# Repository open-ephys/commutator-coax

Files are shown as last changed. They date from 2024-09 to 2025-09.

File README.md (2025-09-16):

# Torque-free Coax Commutator

The wide-spread availability of 6 degree of freedom pose tracking using internal-measurement units
(IMUs) allows continuous monitoring of an animal's rotational state in an environment. This obviates
the need for tether torque measurements to drive an active commutator since the rotational state of
the animal is known in real-time, and the commutator can simply follow along. This permits the use
of extremely thin [coaxial tethers](https://open-ephys.org/tethers) that cannot function with a
standard active commutator because they are too flexible to translate rotational torque.

Zero-torque coaxial commutator.

This commutator functions with serialized headstages and miniscopes (such as [ONIX
headstages](https://open-ephys.github.io/onix-docs/index.html) and UCLA Miniscope 4.0) that provide
orientation data. It can also be used with a coaxial headstage/miniscope without an IMU, using
video-based rotation tracking since its JSON-based command protocol over serial is agnostic to how
rotational measurements are taken. 

For more information, visit the [commutator docs](https://open-ephys.github.io/commutator-docs/).

## Bill of Materials (BOM)

The following BOM pertains to the commutator's mechanical design. You can find the electronics BOM in the [commutator-controller repo](https://github.com/open-ephys/commutator-controller/tree/main/pcb/manufacturing/bom).

| Qty. | Part | Part No. | Description | Link |
| --- | --- | --- | --- | --- |
| 1	| RF Rotary Joint	|	BN 835047C0010 | SMA-f (50 Ω), DC-18 GHz | [link](https://products.spinner-group.com/1-channel-coaxial-rotary-joint-sma-female-dc-18-ghz-bn835047C0011) |
| 1 | NEMA 11 motor | 11HS18-0674S | 45mm length, 1.8 deg step angle, ~600mA max | [link](https://www.omc-stepperonline.com/nema-11-bipolar-1-8deg-9-5ncm-13-5oz-in-0-67a-4-6v-28x28x45mm-4-wires-11hs18-0674s) |
| 1 | 3D printed case | Custom part | 3D printed | [link](https://github.com/open-ephys/commutator-coax/tree/main/mechanical/production) |
| 1 | 3D printed motor gear | Custom part | 3D printed | [link](https://github.com/open-ephys/commutator-coax/tree/main/mechanical/production) | 
| 1 | 3D printed commutator gear | Custom part | 3D printed | [link](https://github.com/open-ephys/commutator-coax/tree/main/mechanical/production) | 
| 3 | M2.5 x 8mm socket head cap screws | 91290A102 | for attaching rotary joint to case | [link](https://www.mcmaster.com/91290A102) |
| 4 | M2.5 x 6mm socket head cap screws | 91290A101 | for attaching motor to case | [link](https://www.mcmaster.com/91290A101) |
| 4 | M2.5 x 8mm button head screws | 91239A756 | for attaching PCB to the case | [link](https://www.mcmaster.com/91239A756) |
| 1 | Control PCB | - | - | [link](https://github.com/open-ephys/commutators/tree/main/pcb/manufacturing/gerber) |
| 1 | eBOM | - | electrical components for assembling the PCB | [link](https://github.com/open-ephys/commutators/blob/main/pcb/manufacturing/bom/oe-commutator-controller.html) |

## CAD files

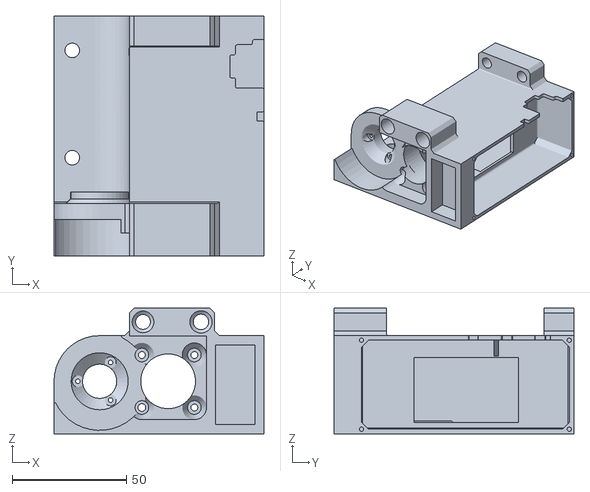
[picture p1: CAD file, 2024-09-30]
mechanical/production/rf_commutator_housing.STL
92.0 x 105.0 x 55.0

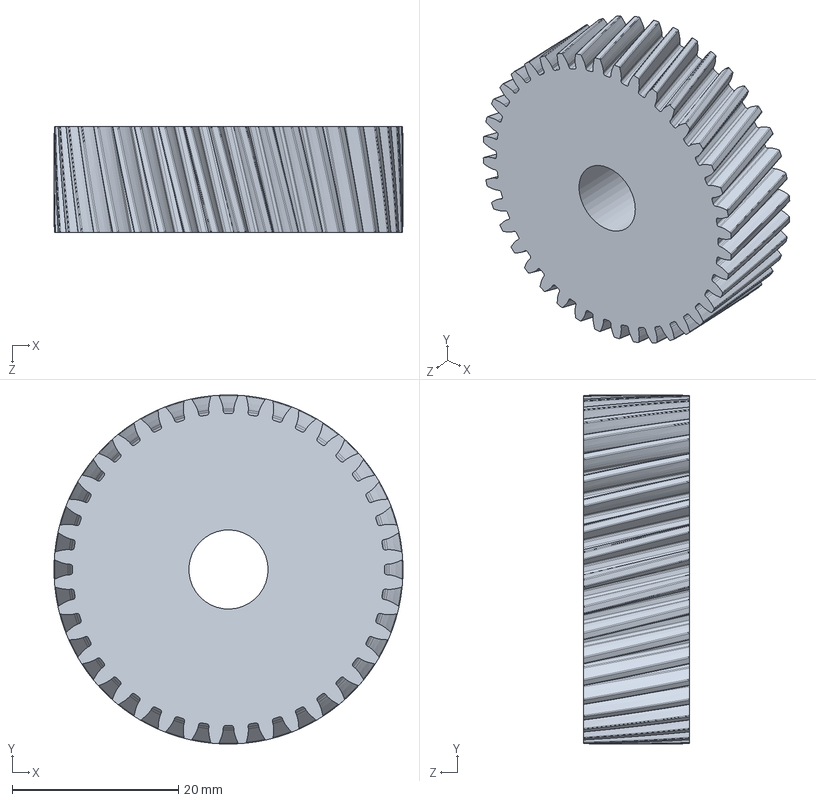
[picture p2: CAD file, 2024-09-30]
mechanical/source/gears/Robust Involute Helical Gear Generator - CCW.SLDPRT
42.0 x 42.0 x 12.7 mm

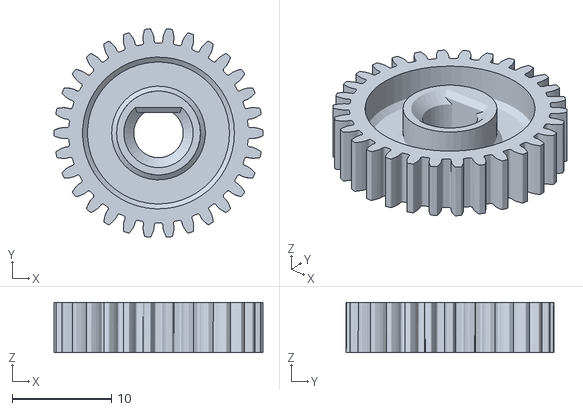
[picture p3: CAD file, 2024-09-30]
mechanical/production/gear_a.STL
21.1 x 21.0 x 5.08

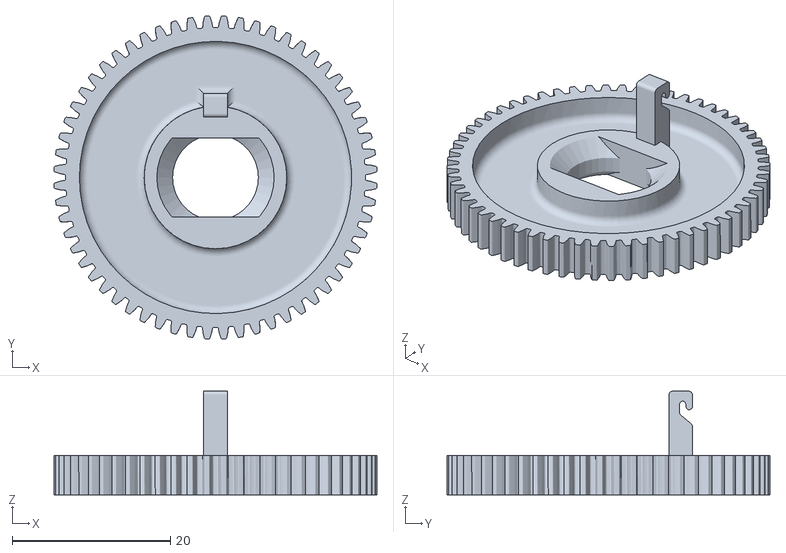
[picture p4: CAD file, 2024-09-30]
mechanical/production/gear_b.STL
40.9 x 40.9 x 13.1

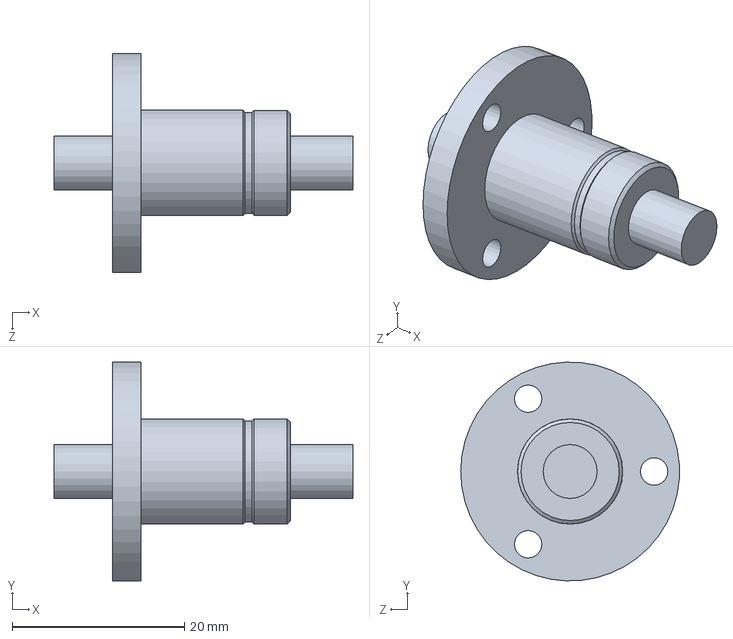
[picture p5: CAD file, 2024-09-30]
mechanical/source/Fairview_FMRJ1002_rf_rotary_jpint_female_to_female_flanged.SLDPRT
34.7 x 25.4 x 25.4 mm

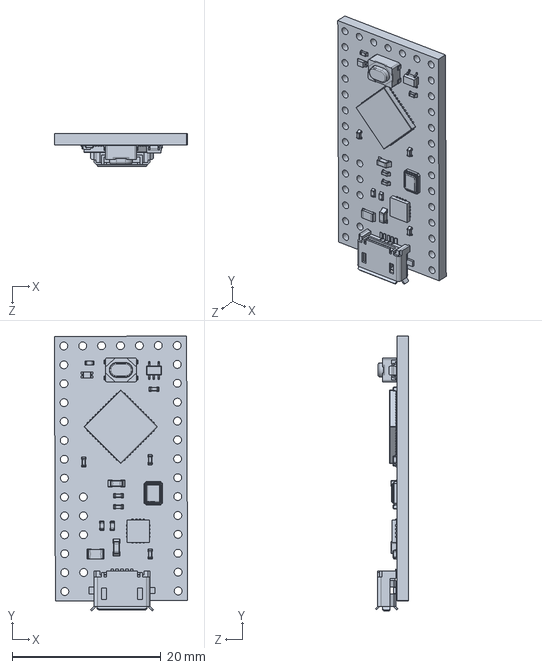
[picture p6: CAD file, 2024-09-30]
mechanical/source/Teensy_lc.SLDPRT
17.9 x 37.0 x 4.49 mm

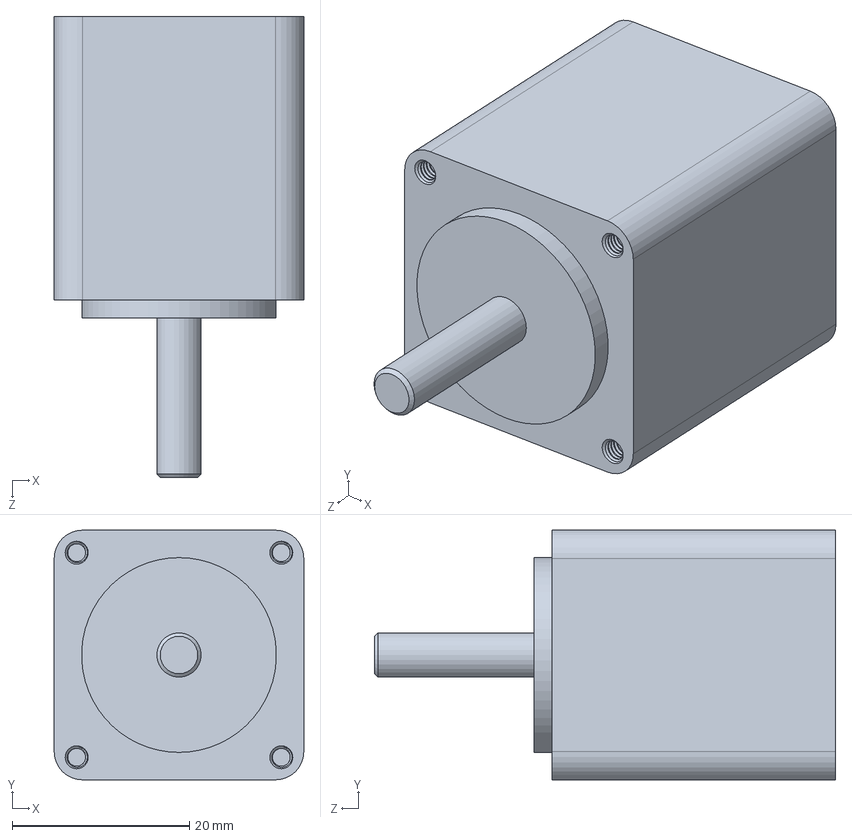
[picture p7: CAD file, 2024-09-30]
mechanical/source/6627T370_POSITION-CONTROL DC MOTOR.SLDPRT
28.2 x 28.2 x 52.1 mm

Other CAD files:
mechanical/source/rf_commutator_housing.SLDPRT
mechanical/source/gears/gear_a.SLDPRT

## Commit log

2024-09-30 Coax commutator enclosure design
    - Derived from a repo called "commutators" 2024/09/24
    [6627T370_POSITION-CONTROL DC MOTOR.SLDPRT, Fairview_FMRJ1002_rf_rotary_jpint_female_to_female_flanged.SLDPRT, Robust Involute Helical Gear Generator - CCW.SLDP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]
2025-03-11 Add bom to readme
2025-03-12 BOM edit - Use the same part number for motor screws and motor screws
2025-03-12 Update README.md
    Add link to electronics BoM
2025-09-16 Update README.md
    Fix screws in BOM
